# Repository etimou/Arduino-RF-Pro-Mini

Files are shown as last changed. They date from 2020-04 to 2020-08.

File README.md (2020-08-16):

# Arduino-RF-Pro-Mini
**Arduino Pro Mini + nRF24L01P = Arduino-RF-Pro-Mini**
- designed with [Kicad](https://kicad-pcb.org/).
- 100% Arduino Pro Mini pin compatible
- embeds nRF24l01+ chip for radio communication
- low power (can run for months on a battery)
- compatible with [MySensors](www.mysensors.org) framework, but not only

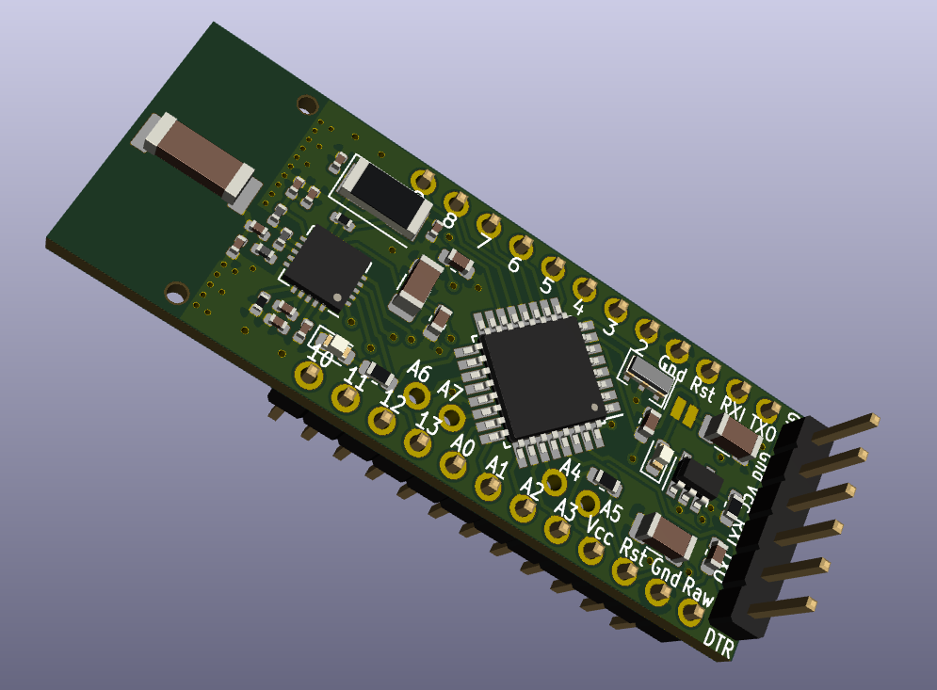
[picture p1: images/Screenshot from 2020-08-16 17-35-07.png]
 
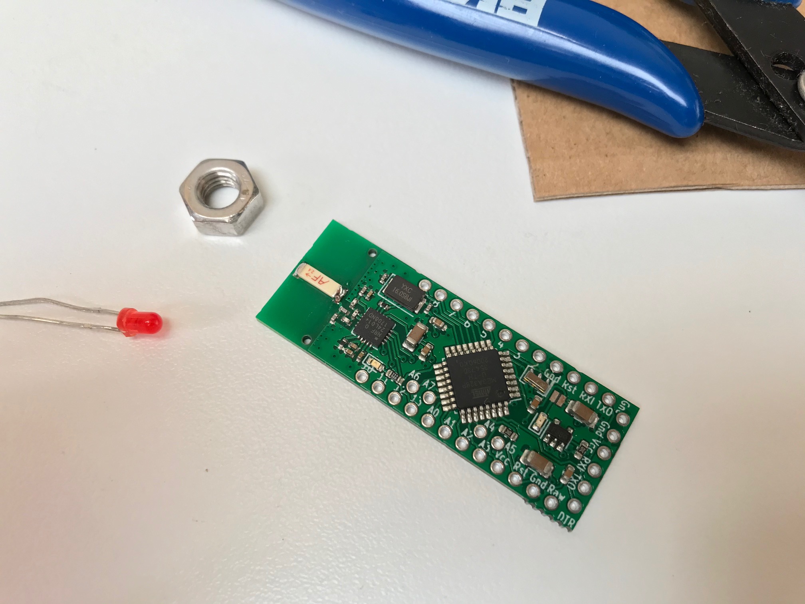
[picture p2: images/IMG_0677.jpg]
 

**Programming the board**

You need to select Arduino Pro or Pro mini, ATmega328P (3.3V, 8MHz) in the Arduino IDE. An USB-Serial adapter that provides 3.3V is required, otherwise the radio chip can be damaged.

**Source code**

The example program consists in a roundtrip message that is sent from a node, using a gateway. You need two modules.

**Special thanks**

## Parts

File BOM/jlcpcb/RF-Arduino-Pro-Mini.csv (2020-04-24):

Comment | Designator | Footprint | LCSC Part #（optional）
nRF24L01P | _U1 | QFN-20-1EP_4x4mm_P0.5mm_EP2.5x2.5mm | C8791
ATmega328P-AU | U1 | TQFP-32_7x7mm_P0.8mm | C14877
0.1uF 10% 50V | C1,C2,C3,C10 | C_0603_1608Metric | C14663
10uF 10% 50V | C13,C19,_C10 | C_1206_3216Metric | C13585
8MHz | Q1 | Resonator_SMD_muRata_CSTxExxV-3Pin_3.0x1.1mm
10K 5% | R2,R11 | R_0603_1608Metric | C25804
2.2K 5% | R6 | R_0603_1608Metric | C4190
MIC5205-3.3YM5 | U2 | SOT-23-5 | C336240
Green | D3 | LED_0603_1608Metric | C72043
Red | LED1 | LED_0603_1608Metric | C2286
22pF NPO, 5%, 50V | _C1,_C2 | C_0402_1005Metric | C1555
2.2nF X7R, 10%, 50V | _C3 | C_0402_1005Metric | C1531
4.7pF NPO, +/- 0.25 pF, 50V | _C4 | C_0402_1005Metric | C1569
1.5pF NPO, +/- 0.1 pF, 50V | _C5 | C_0402_1005Metric | C1552
1.0pF NPO, +/- 0.1 pF, 50V | _C6 | C_0402_1005Metric | C1550
33nF X7R, 10%, 50V | _C7 | C_0402_1005Metric | C1585
1nF X7R, 10%, 50V | _C8 | C_0402_1005Metric | C1523
10nF X7R, 10%, 50V | _C9 | C_0402_1005Metric | C15195
8.2nH 5% | _L1 | L_0402_1005Metric | C16208
2.7nH 5% | _L2 | L_0402_1005Metric | C27123
3.9nH 5% | _L3 | L_0402_1005Metric | C14033
1M 5% | _R1 | R_0402_1005Metric | C26083
22K 1% | _R2 | R_0402_1005Metric | C25768
16 MHz | X1 | Crystal_SMD_5032-2Pin_5.0x3.2mm | C112572

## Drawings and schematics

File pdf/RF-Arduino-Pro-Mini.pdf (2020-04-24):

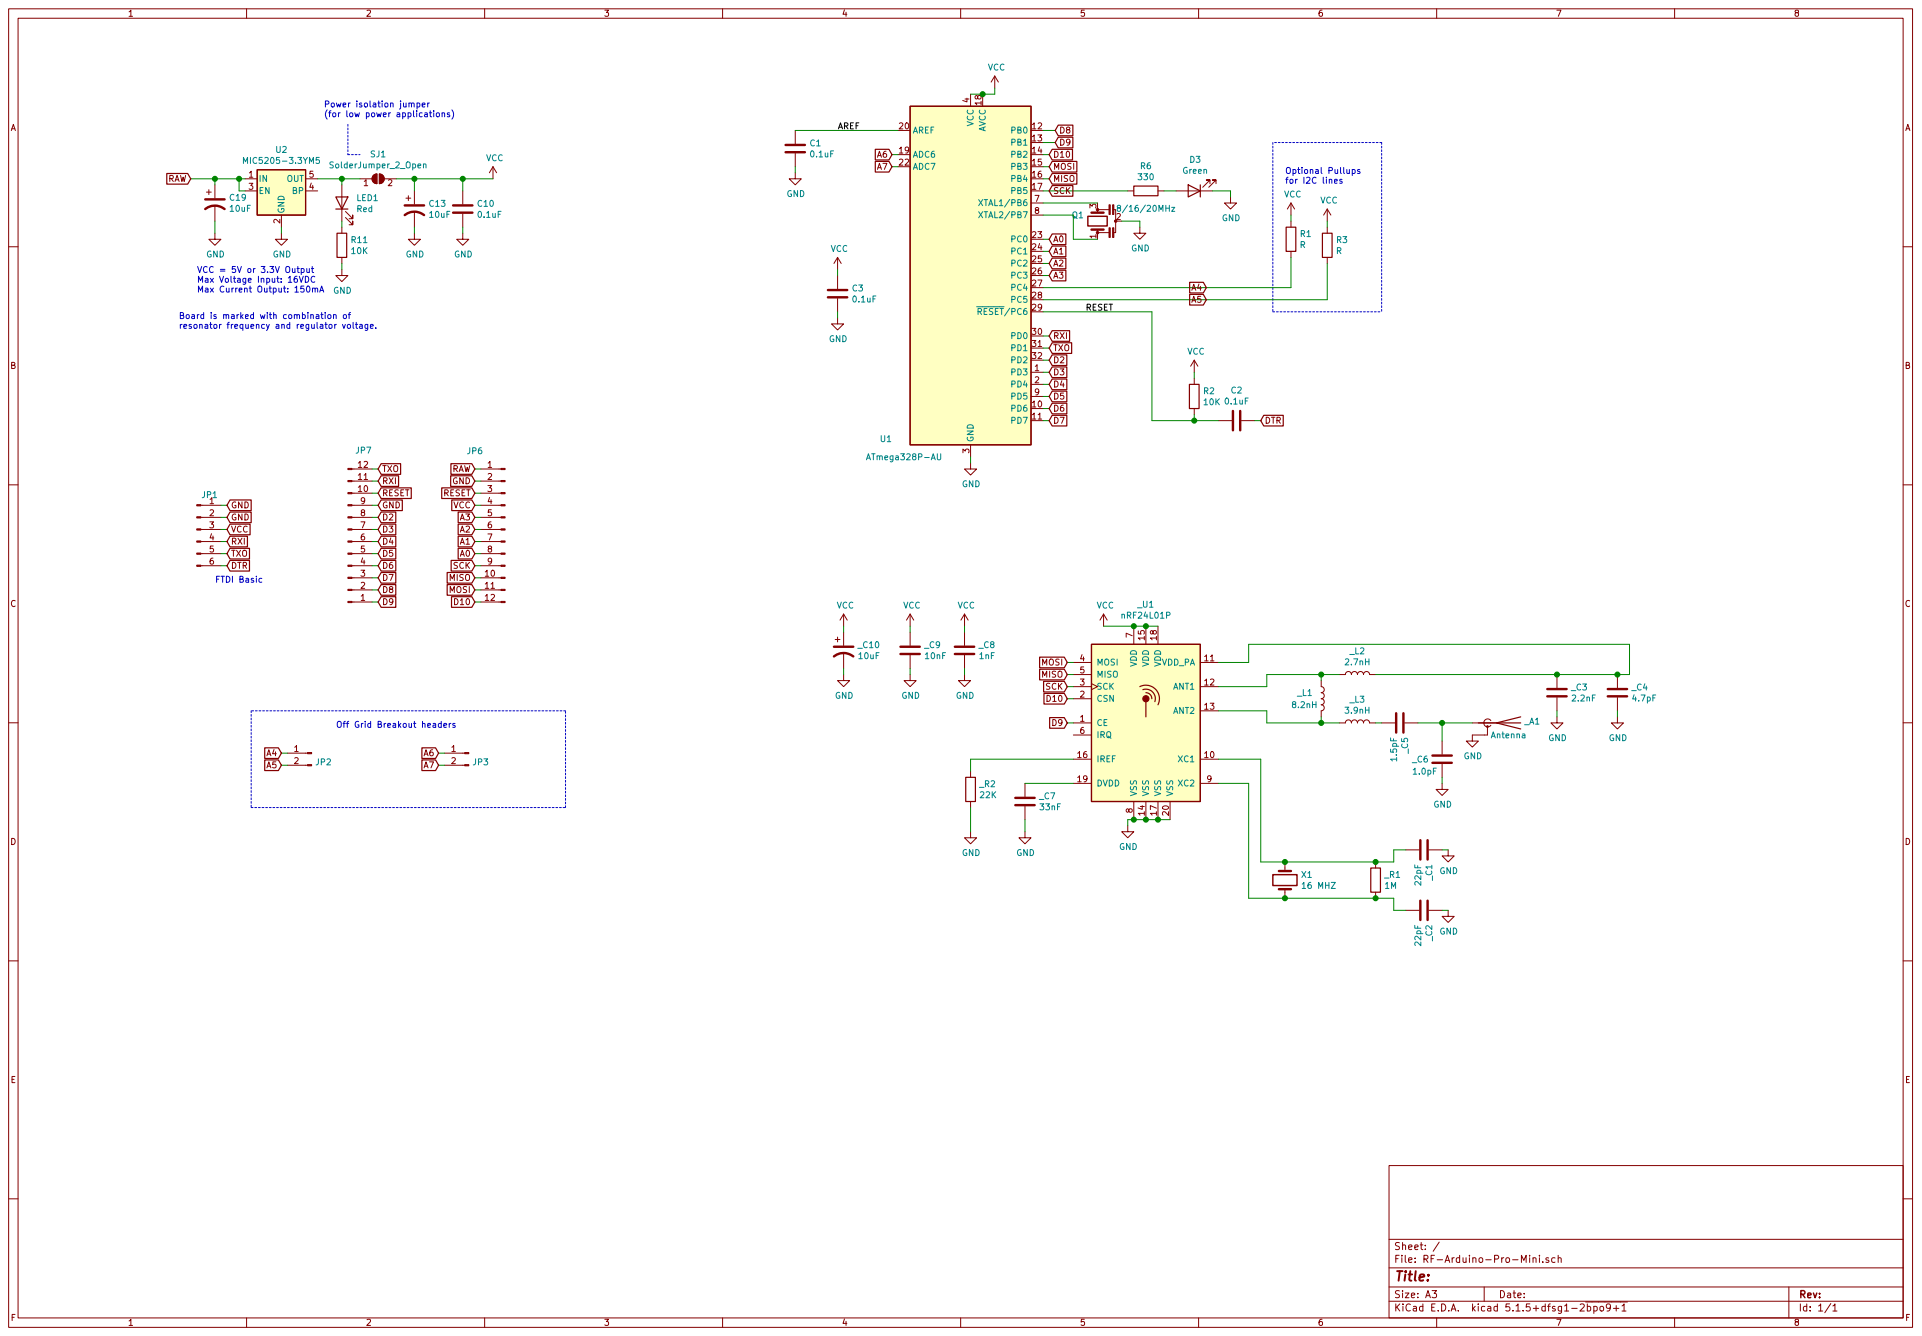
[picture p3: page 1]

2 EN 3 BP 4 OUT 5 U2 MIC5205-3.3YM5 GND GND GND

for I2C lines Board is marked with combination of resonator frequency and regulator voltage.

D10 D9 SCK MISO MOSI D3 GND
D4 D5 VCC

Id: 1/1 Title: File: RF-Arduino-Pro-Mini.sch Sheet: /

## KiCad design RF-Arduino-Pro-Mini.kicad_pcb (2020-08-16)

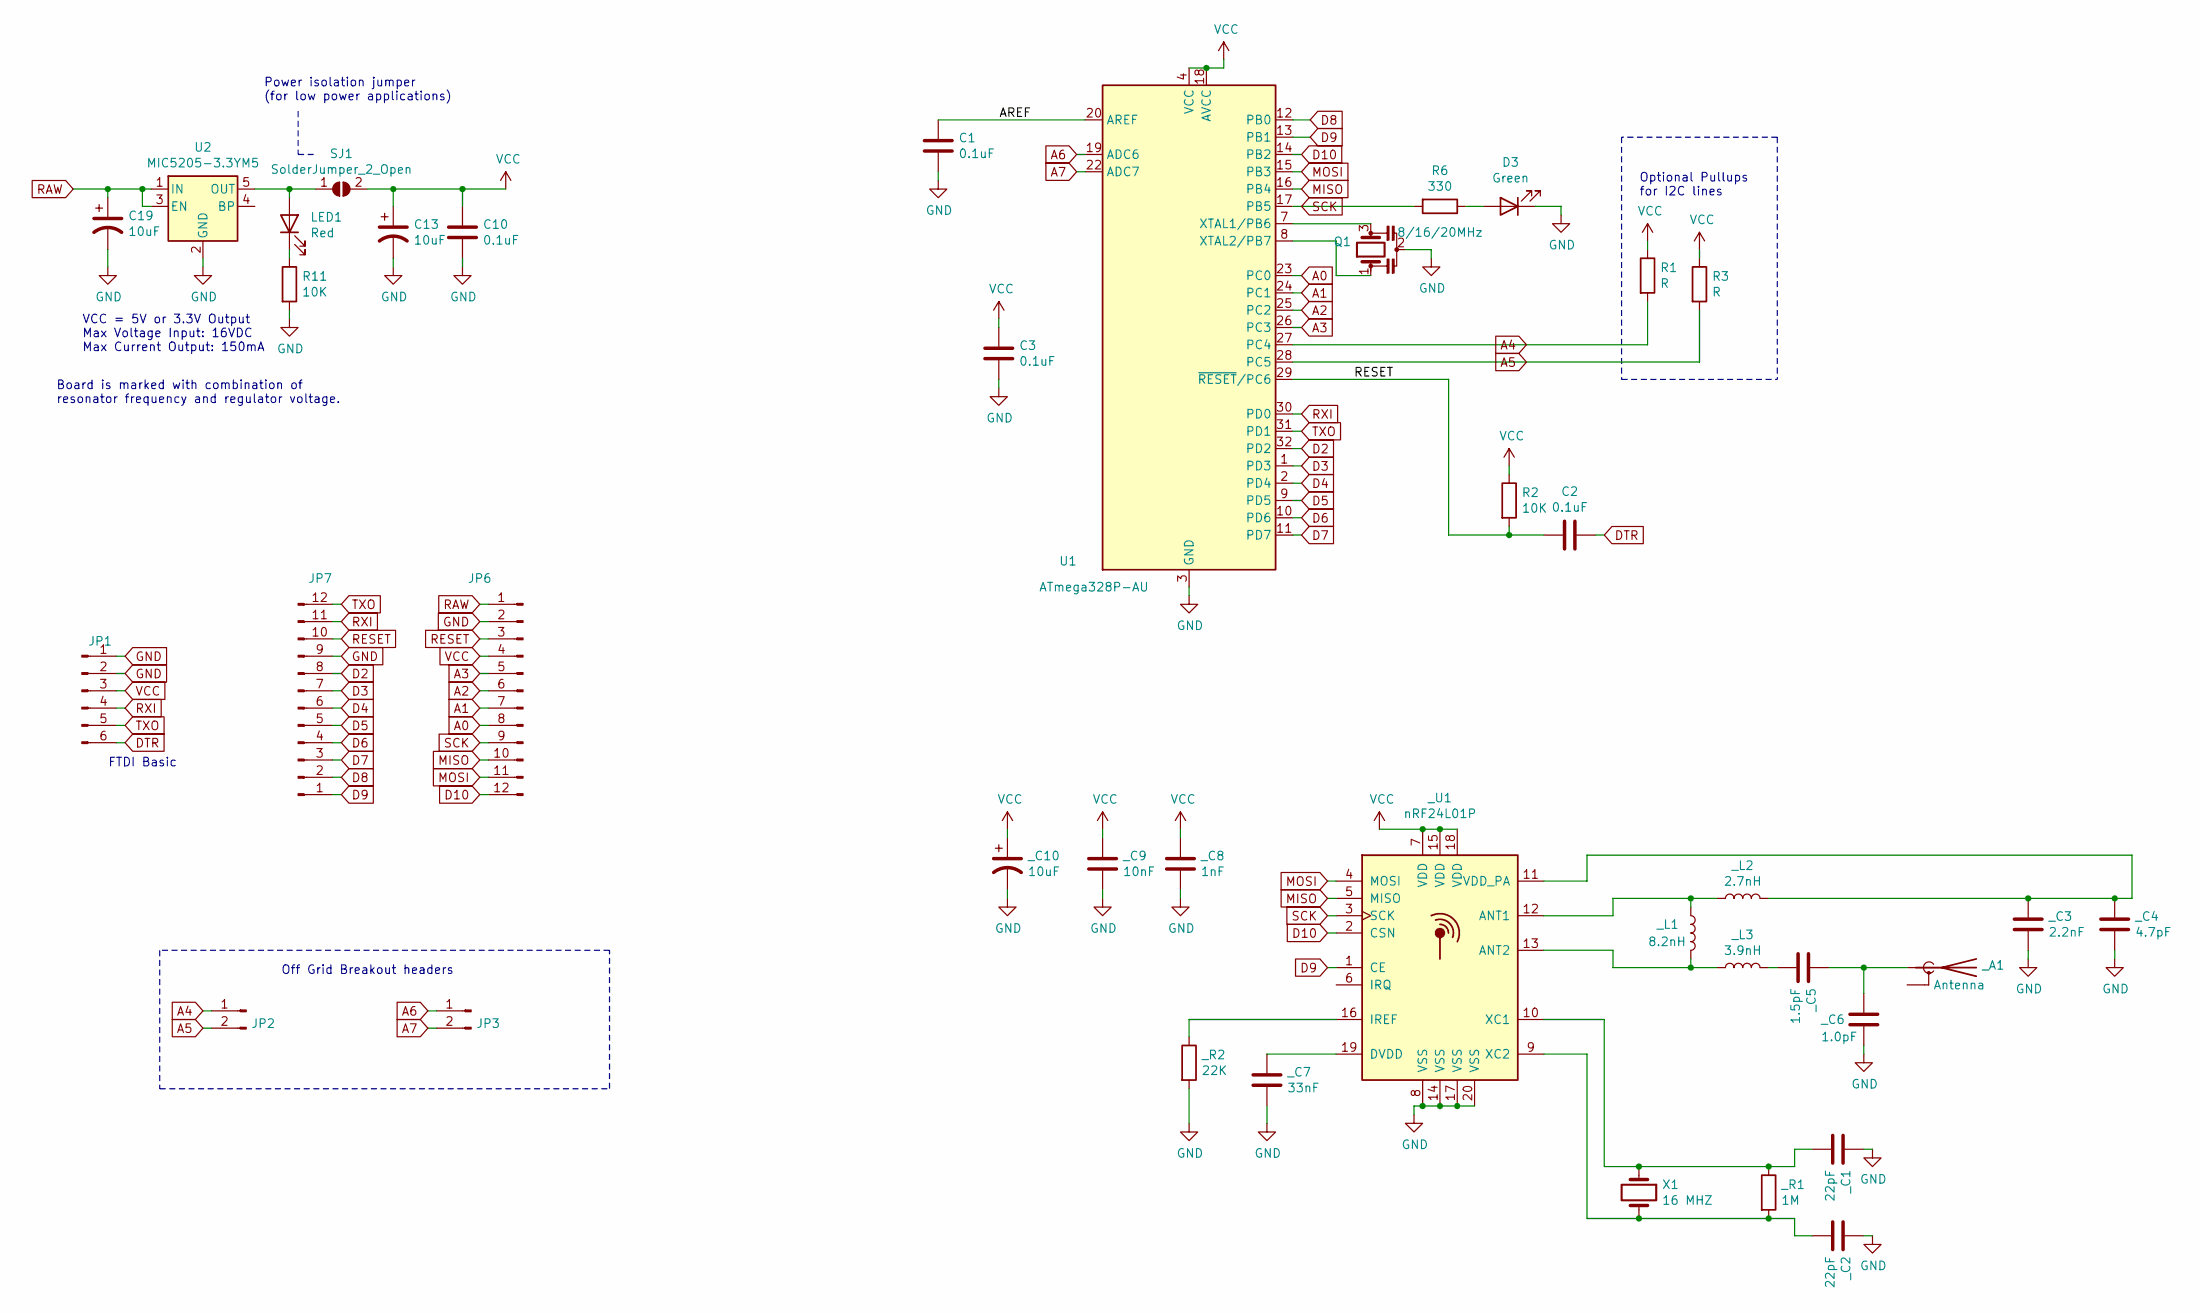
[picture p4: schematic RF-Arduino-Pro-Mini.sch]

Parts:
C1, C2, C3, C10: 0.1uF; C_0603_1608Metric
C13, C19: 10uF; C_1206_3216Metric
D3: Green; LED_0603_1608Metric
JP1: Conn_01x06_Male; PinHeader_1x06_P2.54mm_Vertical
JP2, JP3: Conn_01x02_Male; PinHeader_1x02_P2.54mm_Vertical
JP6, JP7: Conn_01x12_Male; PinHeader_1x12_P2.54mm_Vertical
LED1: Red; LED_0603_1608Metric
Q1: 8/16/20MHz; Resonator_SMD_muRata_CSTxExxV-3Pin_3.0x1.1mm
R1, R3: R; R_0603_1608Metric
R2, R11: 10K; R_0603_1608Metric
R6: 330; R_0603_1608Metric
SJ1: SolderJumper_2_Open; SolderJumper-2_P1.3mm_Open_Pad1.0x1.5mm
U1: ATmega328P-AU; TQFP-32_7x7mm_P0.8mm
U2: MIC5205-3.3YM5; SOT-23-5
X1: 16 MHZ; Crystal_SMD_5032-2Pin_5.0x3.2mm
_A1: Antenna; ANT-2.45-CHP
_C1, _C2: 22pF; C_0402_1005Metric
_C3: 2.2nF; C_0402_1005Metric
_C4: 4.7pF; C_0402_1005Metric
_C5: 1.5pF; C_0402_1005Metric
_C6: 1.0pF; C_0402_1005Metric
_C7: 33nF; C_0402_1005Metric
_C8: 1nF; C_0402_1005Metric
_C9: 10nF; C_0402_1005Metric
_C10: 10uF; C_1206_3216Metric
_L1: 8.2nH; L_0402_1005Metric
_L2: 2.7nH; L_0402_1005Metric
_L3: 3.9nH; L_0402_1005Metric
_R1: 1M; R_0402_1005Metric
_R2: 22K; R_0402_1005Metric
_U1: nRF24L01P; QFN-20-1EP_4x4mm_P0.5mm_EP2.5x2.5mm

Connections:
/AREF: C1.1, U1.20 (AREF)
A0: JP6.8, U1.23 (PC0)
A1: JP6.7, U1.24 (PC1)
A2: JP6.6, U1.25 (PC2)
A3: JP6.5, U1.26 (PC3)
A4: JP2.1, R1.2, U1.27 (PC4)
A5: JP2.2, R3.2, U1.28 (PC5)
A6: JP3.1, U1.19 (ADC6)
A7: JP3.2, U1.22 (ADC7)
D2: JP7.8, U1.32 (PD2)
D3: JP7.7, U1.1 (PD3)
D4: JP7.6, U1.2 (PD4)
D5: JP7.5, U1.9 (PD5)
D6: JP7.4, U1.10 (PD6)
D7: JP7.3, U1.11 (PD7)
D8: JP7.2, U1.12 (PB0)
D9: JP7.1, U1.13 (PB1), _U1.1 (CE)
D10: JP6.12, U1.14 (PB2), _U1.2 (CSN)
DTR: C2.1, JP1.6
GND: C1.2, C3.2, C10.2, C13.2, C19.2, D3.1 (K), JP1.1, JP1.2, JP6.2, JP7.9, Q1.2, R11.2, U1.3 (GND), U1.5 (GND), U1.21 (GND), U2.2 (GND), _C1.1, _C2.1, _C3.2, _C4.2, _C6.2, _C7.2, _C8.2, _C9.2, _C10.2, _R2.2, _U1.8 (VSS), _U1.14 (VSS), _U1.17 (VSS), _U1.20 (VSS)
MISO: JP6.10, U1.16 (PB4), _U1.5 (MISO)
MOSI: JP6.11, U1.15 (PB3), _U1.4 (MOSI)
unnamed: D3.2 (A), R6.1
unnamed: LED1.1 (K), R11.1
unnamed: LED1.2 (A), SJ1.1 (A), U2.5 (OUT)
unnamed: Q1.1, U1.8 (XTAL2/PB7)
unnamed: Q1.3, U1.7 (XTAL1/PB6)
unnamed: X1.1, _C1.2, _R1.1, _U1.10 (XC1)
unnamed: X1.2, _C2.2, _R1.2, _U1.9 (XC2)
unnamed: _A1.1 (A), _C5.1, _C6.1
unnamed: _C3.1, _C4.1, _L2.2, _U1.11 (VDD_PA)
unnamed: _C5.2, _L3.2
unnamed: _C7.1, _U1.19 (DVDD)
unnamed: _L1.1, _L2.1, _U1.12 (ANT1)
unnamed: _L1.2, _L3.1, _U1.13 (ANT2)
unnamed: _R2.1, _U1.16 (IREF)
RAW: C19.1, JP6.1, U2.1 (IN), U2.3 (EN)
RESET: C2.2, JP6.3, JP7.10, R2.2, U1.29 (~RESET~/PC6)
RXI: JP1.4, JP7.11, U1.30 (PD0)
SCK: JP6.9, R6.2, U1.17 (PB5), _U1.3 (SCK)
TXO: JP1.5, JP7.12, U1.31 (PD1)
VCC: C3.1, C10.1, C13.1, JP1.3, JP6.4, R1.1, R2.1, R3.1, SJ1.2 (B), U1.4 (VCC), U1.6 (VCC), U1.18 (AVCC), _C8.1, _C9.1, _C10.1, _U1.7 (VDD), _U1.15 (VDD), _U1.18 (VDD)

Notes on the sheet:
Off Grid Breakout headers
Optional Pullups for I2C lines
FTDI Basic
Power isolation jumper (for low power applications)
VCC = 5V or 3.3V Output Max Voltage Input: 16VDC Max Current Output: 150mA
Board is marked with combination of resonator frequency and regulator voltage.

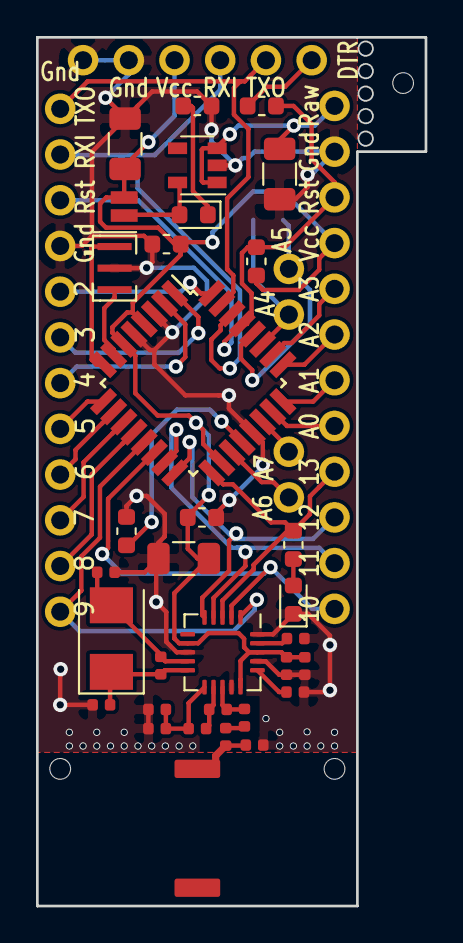
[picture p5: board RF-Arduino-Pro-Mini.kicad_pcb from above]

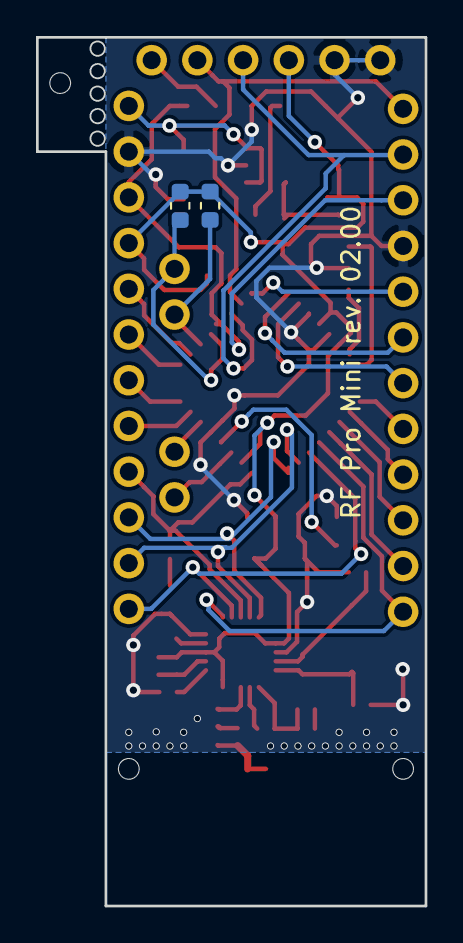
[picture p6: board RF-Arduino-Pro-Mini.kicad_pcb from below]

Board: 2 copper layers, 21.6 x 48.3 mm, 40 parts (2 on the bottom side), 42 nets.

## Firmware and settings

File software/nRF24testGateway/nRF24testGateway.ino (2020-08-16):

/*
* Getting Started example sketch for nRF24L01+ radios
* This is a very basic example of how to send data from one node to another
* Updated: Dec 2014 by TMRh20
*/

#include <SPI.h>
#include "RF24.h"

/****************** User Config ***************************/
/***      Set this radio as radio number 0 or 1         ***/
bool radioNumber = 0;

/* Hardware configuration: Set up nRF24L01 radio on SPI bus plus pins 7 & 8 */
RF24 radio(9, 10);
/**********************************************************/

byte addresses[][6] = {"EFEFE","ABABA"};

// Used to control whether this node is sending or receiving
bool role = 0;

void setup() {
  Serial.begin(115200);
  Serial.println(F("RF24/examples/GettingStarted"));
  Serial.println(F("*** PRESS 'T' to begin transmitting to the other node"));
  
  radio.begin();

  // Set the PA Level low to prevent power supply related issues since this is a
 // getting_started sketch, and the likelihood of close proximity of the devices. RF24_PA_MAX is default.
  radio.setPALevel(RF24_PA_MAX);
  radio.setDataRate(RF24_250KBPS);
  
  // Open a writing and reading pipe on each radio, with opposite addresses
  if(radioNumber){
    radio.openWritingPipe(addresses[1]);
    radio.openReadingPipe(1,addresses[0]);
  }else{
    radio.openWritingPipe(addresses[0]);
    radio.openReadingPipe(1,addresses[1]);
  }
  
  // Start the radio listening for data
  radio.startListening();
}

void loop() {
  
  
/****************** Ping Out Role ***************************/  
if (role == 1)  {
    
    radio.stopListening();                                    // First, stop listening so we can talk.
    
    
    Serial.println(F("Now sending"));

    unsigned long start_time = micros();                             // Take the time, and send it.  This will block until complete
     if (!radio.write( &start_time, sizeof(unsigned long) )){
       Serial.println(F("failed"));
     }
        
    radio.startListening();                                    // Now, continue listening
    
    unsigned long started_waiting_at = micros();               // Set up a timeout period, get the current microseconds
    boolean timeout = false;                                   // Set up a variable to indicate if a response was received or not
    
    while ( ! radio.available() ){                             // While nothing is received
      if (micros() - started_waiting_at > 200000 ){            // If waited longer than 200ms, indicate timeout and exit while loop
          timeout = true;
          break;
      }      
    }
        
    if ( timeout ){                                             // Describe the results
        Serial.println(F("Failed, response timed out."));
    }else{
        unsigned long got_time;                                 // Grab the response, compare, and send to debugging spew
        radio.read( &got_time, sizeof(unsigned long) );
        unsigned long end_time = micros();
        
        // Spew it
        Serial.print(F("Sent "));
        Serial.print(start_time);
        Serial.print(F(", Got response "));
        Serial.print(got_time);
        Serial.print(F(", Round-trip delay "));
        Serial.print(end_time-start_time);
        Serial.println(F(" microseconds"));
    }

    // Try again 1s later
    delay(1000);
  }



/****************** Pong Back Role ***************************/

  if ( role == 0 )
  {
    unsigned long got_time;
    
    if( radio.available()){
                                                                    // Variable for the received timestamp
      while (radio.available()) {                                   // While there is data ready
        radio.read( &got_time, sizeof(unsigned long) );             // Get the payload
      }
     
      radio.stopListening();                                        // First, stop listening so we can talk   
      radio.write( &got_time, sizeof(unsigned long) );              // Send the final one back.      
      radio.startListening();                                       // Now, resume listening so we catch the next packets.     
      Serial.print(F("Sent response "));
      Serial.println(got_time);  
   }
 }




/****************** Change Roles via Serial Commands ***************************/

  if ( Serial.available() )
  {
    char c = toupper(Serial.read());
    if ( c == 'T' && role == 0 ){      
      Serial.println(F("*** CHANGING TO TRANSMIT ROLE -- PRESS 'R' TO SWITCH BACK"));
      role = 1;                  // Become the primary transmitter (ping out)
    
   }else
    if ( c == 'R' && role == 1 ){
      Serial.println(F("*** CHANGING TO RECEIVE ROLE -- PRESS 'T' TO SWITCH BACK"));      
       role = 0;                // Become the primary receiver (pong back)
       radio.startListening();
       
    }
  }


} // Loop
